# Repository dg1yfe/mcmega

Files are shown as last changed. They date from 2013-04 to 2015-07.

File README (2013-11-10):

MCmega is a port of the MC70 firmware to the AVR platform.
It provides an alternative firmware for Motorola MC micro transceivers to enable the use of those radios for HAM radio.
The project includes a PCB (printed ciruit board) with an ATMega64 which is designed to replace the original CPU on the GLN6628B/GLN6984A command board used in the MC micro model EZA9.

Check out the details on the projects homepage:
http://mc70.stus-disco.de

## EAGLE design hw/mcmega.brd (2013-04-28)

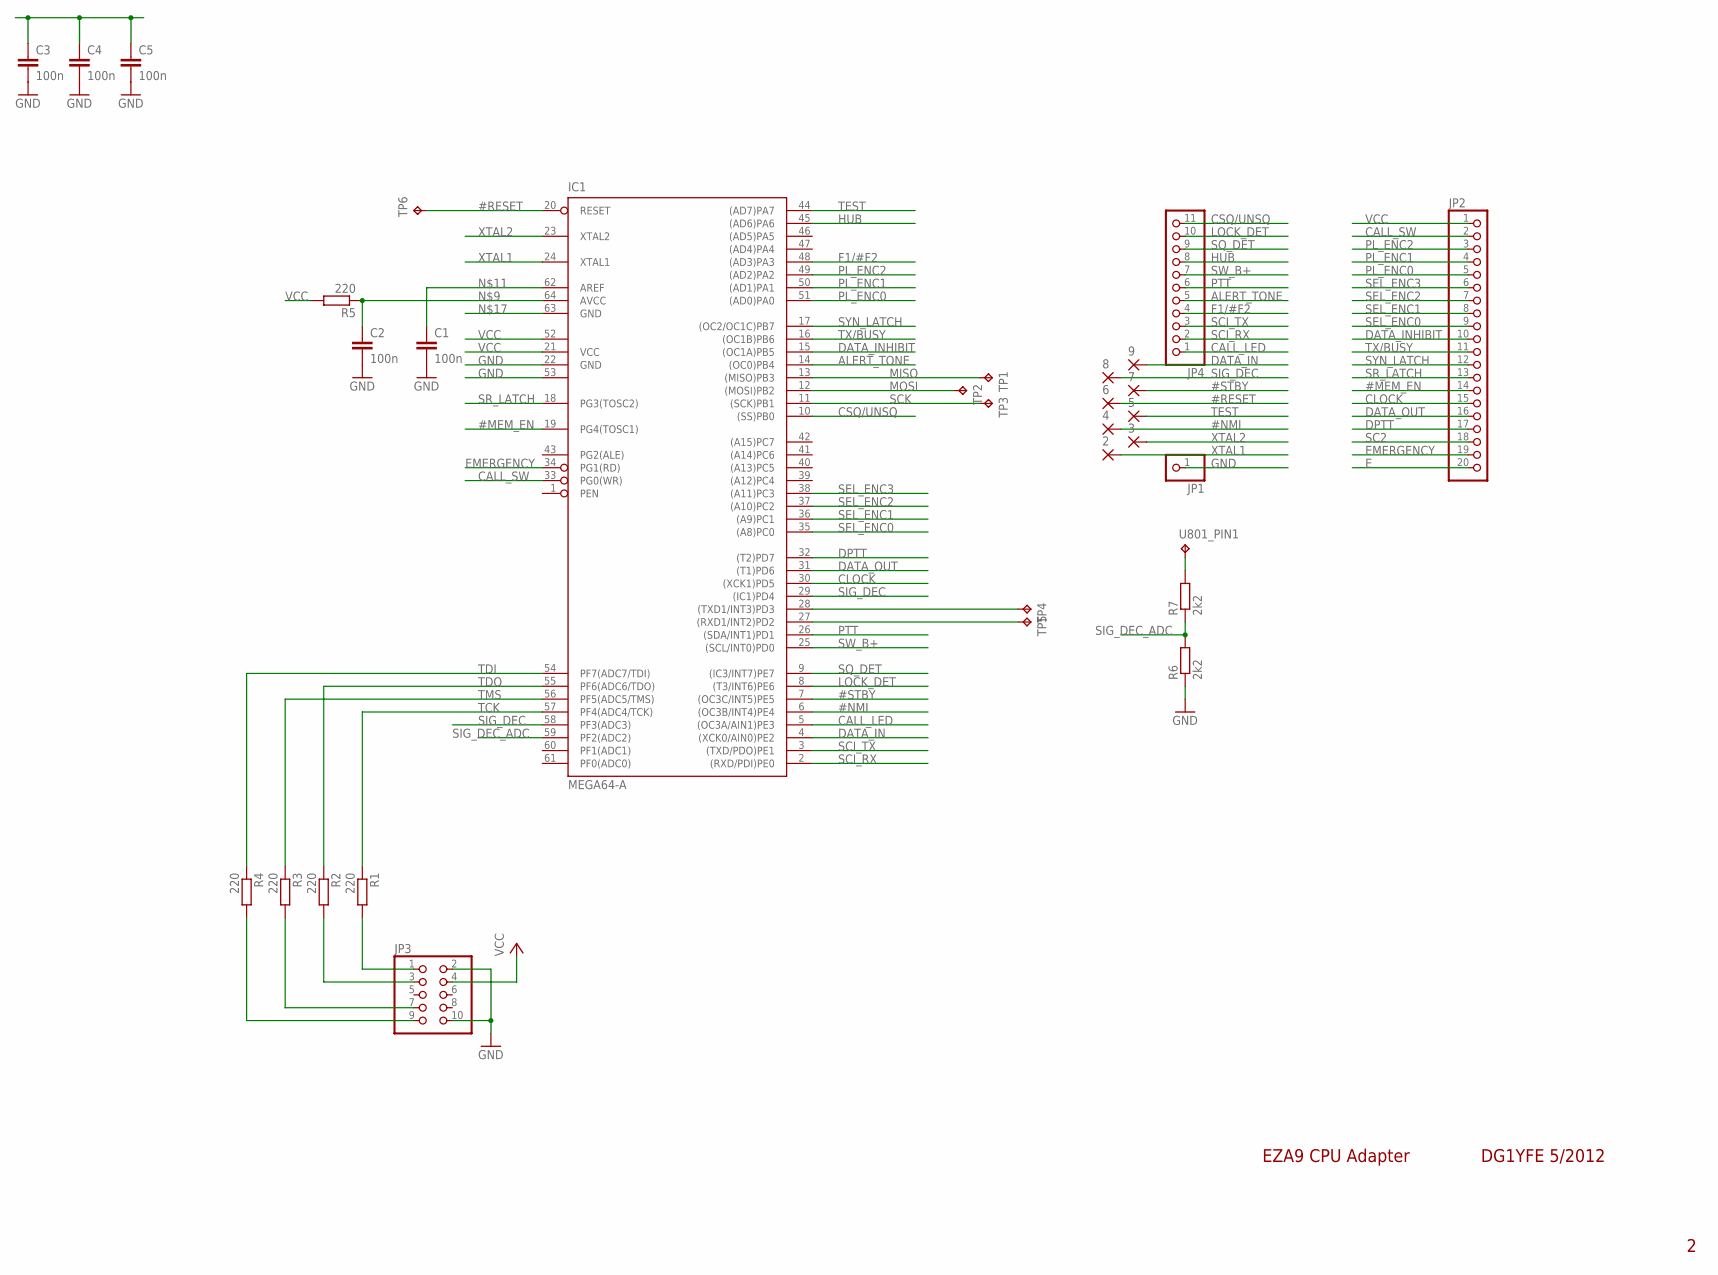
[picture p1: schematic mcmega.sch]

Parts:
2, 3, 4, 5, 6, 7, 8, 9: SMD2; SMD1,27-2,54
C1, C2, C3, C4, C5: 100n; C0603
IC1: MEGA64-A; TQFP64
JP1: PINHD-1X1; 1X01
JP2: PINHD-1X20; 1X20
JP3: PINHD-2X5; 2X05
JP4: PINHD-1X11; 1X11
R1, R2, R3, R4, R5: 220; R0603
R6, R7: 2k2; R0603
TP1, TP2, TP3, TP4, TP5, TP6: TPTP09R; TP09R
U801_PIN1: TPTP10R; TP10R

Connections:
#MEM_EN: IC1.19 (PG4(TOSC1)), JP2.14
#NMI: 4.1, IC1.6 ((OC3B/INT4)PE4)
#RESET: 6.1, IC1.20 (RESET), TP6.TP
#STBY: 7.1, IC1.7 ((OC3C/INT5)PE5)
ALERT_TONE: IC1.14 ((OC0)PB4), JP4.5
CALL_LED: IC1.5 ((OC3A/AIN1)PE3), JP4.1
CALL_SW: IC1.33 (PG0(WR)), JP2.2
CLOCK: IC1.30 ((XCK1)PD5), JP2.15
CSQ/UNSQ: IC1.10 ((SS)PB0), JP4.11
DATA_IN: 9.1, IC1.4 ((XCK0/AIN0)PE2)
DATA_INHIBIT: IC1.15 ((OC1A)PB5), JP2.10
DATA_OUT: IC1.31 ((T1)PD6), JP2.16
DPTT: IC1.32 ((T2)PD7), JP2.17
E: JP2.20
EMERGENCY: IC1.34 (PG1(RD)), JP2.19
F1/#F2: IC1.48 ((AD3)PA3), JP4.4
GND: C1.2, C2.2, C3.2, C4.2, C5.2, IC1.22 (GND), IC1.53 (GND1), JP1.1, JP3.2, JP3.10, R6.1
HUB: IC1.45 ((AD6)PA6), JP4.8
LOCK_DET: IC1.8 ((T3/INT6)PE6), JP4.10
MISO: IC1.13 ((MISO)PB3), TP1.TP
MOSI: IC1.12 ((MOSI)PB2), TP2.TP
unnamed: JP3.1, R1.2
unnamed: JP3.3, R2.2
unnamed: JP3.7, R3.2
unnamed: JP3.9, R4.2
unnamed: R7.2, U801_PIN1.TP
unnamed: C2.1, IC1.64 (AVCC), R5.1
unnamed: C1.1, IC1.62 (AREF)
unnamed: IC1.28 ((TXD1/INT3)PD3), TP4.TP
unnamed: IC1.27 ((RXD1/INT2)PD2), TP5.TP
PL_ENC0: IC1.51 ((AD0)PA0), JP2.5
PL_ENC1: IC1.50 ((AD1)PA1), JP2.4
PL_ENC2: IC1.49 ((AD2)PA2), JP2.3
PTT: IC1.26 ((SDA/INT1)PD1), JP4.6
SC2: JP2.18
SCI_RX: IC1.2 ((RXD/PDI)PE0), JP4.2
SCI_TX: IC1.3 ((TXD/PDO)PE1), JP4.3
SCK: IC1.11 ((SCK)PB1), TP3.TP
SEL_ENC0: IC1.35 ((A8)PC0), JP2.9
SEL_ENC1: IC1.36 ((A9)PC1), JP2.8
SEL_ENC2: IC1.37 ((A10)PC2), JP2.7
SEL_ENC3: IC1.38 ((A11)PC3), JP2.6
SIG_DEC: 8.1, IC1.29 ((IC1)PD4), IC1.58 (PF3(ADC3))
SIG_DEC_ADC: IC1.59 (PF2(ADC2)), R6.2, R7.1
SQ_DET: IC1.9 ((IC3/INT7)PE7), JP4.9
SR_LATCH: IC1.18 (PG3(TOSC2)), JP2.13
SW_B+: IC1.25 ((SCL/INT0)PD0), JP4.7
SYN_LATCH: IC1.17 ((OC2/OC1C)PB7), JP2.12
TCK: IC1.57 (PF4(ADC4/TCK)), R1.1
TDI: IC1.54 (PF7(ADC7/TDI)), R4.1
TDO: IC1.55 (PF6(ADC6/TDO)), R2.1
TEST: 5.1, IC1.44 ((AD7)PA7)
TMS: IC1.56 (PF5(ADC5/TMS)), R3.1
TX/BUSY: IC1.16 ((OC1B)PB6), JP2.11
VCC: C3.1, C4.1, C5.1, IC1.21 (VCC), IC1.52 (VCC1), JP2.1, JP3.4, R5.2
XTAL1: 2.1, IC1.24 (XTAL1)
XTAL2: 3.1, IC1.23 (XTAL2)

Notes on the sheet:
EZA9 CPU Adapter
DG1YFE 5/2012

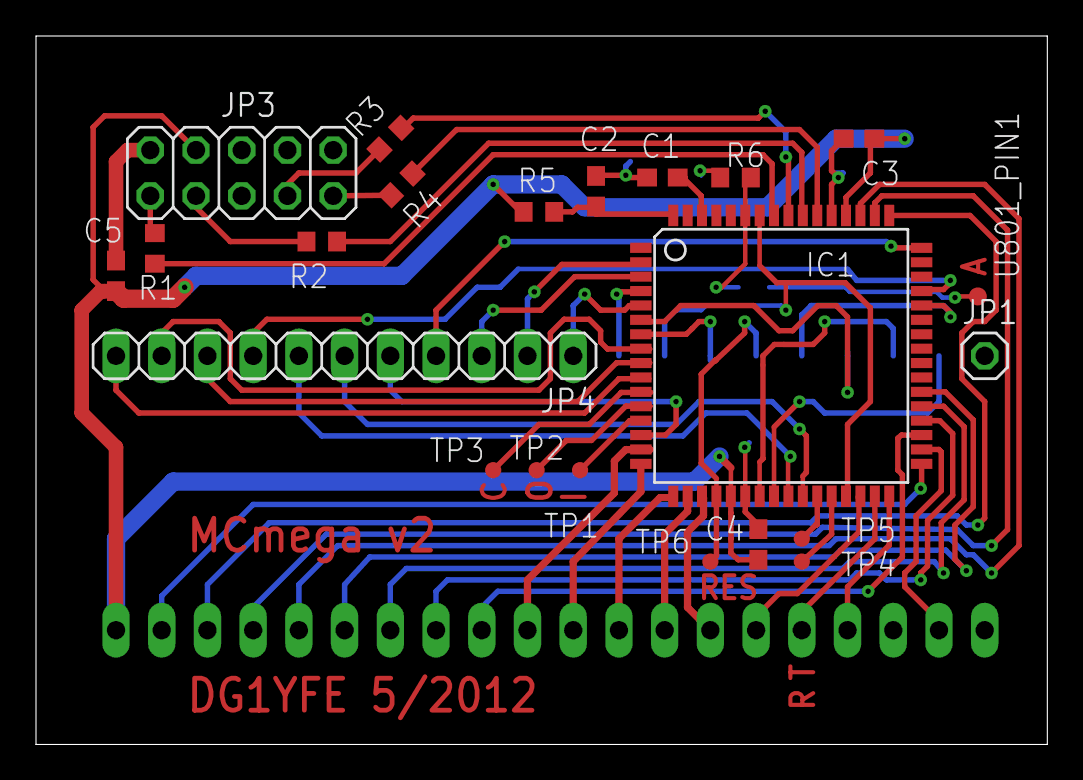
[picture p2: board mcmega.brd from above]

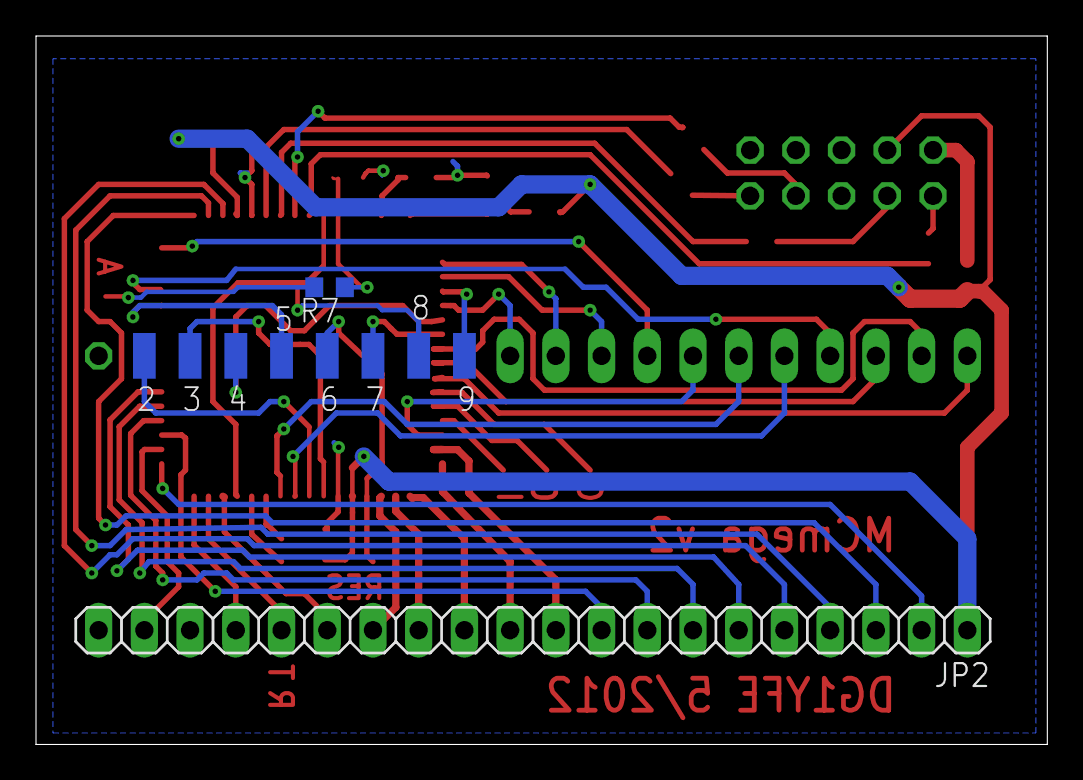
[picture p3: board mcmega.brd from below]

Board: 2 copper layers, 56.2 x 39.4 mm, 32 parts (10 on the bottom side), 55 nets.

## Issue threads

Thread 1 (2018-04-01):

Fuses missing

dg8ygz, 2018-04-01:
No Fuses for the ATMEGA were documented
if there's any additional info needed it would be helpful to know

73s

dg8ygz, 2018-04-01:
FUSES:
low:  **0xD4**
high: **0x10**
ext.:   **0xFF**

necessary:
(in AVR Studio 7)
/Toolchain/AVR GNU Compiler/ Symbols/
**F_CPU=8000000**

/Toolchain/AVR GNU Compiler/Optimization/
**set level to Size   (Os)**
other Flags:
**-Ttext=0xF800**

then it should work with the programm adapter shown here with 8N1 19200

tnx to dg1yfe for info

dg1yfe, 2018-04-02:
Bug and solution relates to https://github.com/dg1yfe/mcmboot/ .

Closed 2018-04-02.

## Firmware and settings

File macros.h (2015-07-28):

/*
 * macros.h
 *
 *  Created on: 26.05.2012
 *****************************************************************************
 *	MCmega - Firmware for the Motorola MC micro radio
 *           to use it as an Amateur-Radio transceiver
 *
 * Copyright (C) 2013 Felix Erckenbrecht, DG1YFE
 *
 * ( AVR port of "MC70"
 *   Copyright (C) 2004 - 2013  Felix Erckenbrecht, DG1YFE)
 *
 * This file is part of MCmega.
 *
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
 ****************************************************************************
 */
#ifndef MACROS_H_
#define MACROS_H_

#include "regmem.h"

#define EZA9

//#define BAND_2M
//#define BAND_70CM

// Timing
// Frequency of crystal in EVA5
#define XTAL F_CPU
// no scaling
#define SYSCLK XTAL
#define MENUTIMEOUT   40	// 4 sek Eingabetimeout
#define PLLCHKTIMEOUT 2		// 200ms Timeout für PLL Check
#define PTT_DEBOUNCE_VAL 20
#define TX_TO_RX_TIME 5		// 5 ms TX -> RX Umschaltung
#define RX_TO_TX_TIME 5  	// 5 ms RX -> TX Umschaltung

#define DEFAULT_RF_PWR 0	// Hi Power (1) / Lo Power (0), only EVA9/EZA9
//************************
// Frequenzkram
//
//
#define RXZF   UINT32_C(21400000)// 21,4 MHz IF (RX VCO has to be 21,4MHz below RX frequency)
#define FREF   UINT32_C(14400000)// 14,4 MHz reference frequency
#define FOFF0  UINT32_C(       0)// Offset0
#define FOFF06 UINT32_C(  600000)// Offset1
#define FOFF76 UINT32_C( 7600000)// Offset2
#define FSTEP  UINT32_C(   12500)// Schrittweite !> 3,5 kHz fuer f<458,3MHz 
								 //( muss groesser sein als Frequenz/(Vorteiler*1023) )
//
#define PLLREF FREF/FSTEP
#define PLLLOCKWAIT 200         // Maximale Wartezeit in ms f�r PLL um einzurasten

//#define FSTEP      6250        // Schrittweite !> 3,5 kHz f�r f<458,3MHz ( mu� gr��er sein als Frequenz/(128*1023) )
//#define PLLREF     1152
//#define PLLREF     2304

#ifdef BAND_70CM
#define FBASE UINT32_C(430000000)// lowest frequency (for eeprom storage) = 140MHz (430 MHz with 70 cm)
#define FBASE_MEM_RECALL UINT32_C(400000000)
#define FDEF  UINT32_C(433500000)// Default Frequency
#define FTXOFF FOFF76			// Default Offset = 7.6 MHz
#define PRESCALER   127         // PLL Prescaler (40 for 2m, 127 for 70cm)
#endif

#ifdef BAND_2M
#define FBASE UINT32_C(140000000)// lowest frequency (for eeprom storage) = 140MHz (430 MHz with 70 cm)
#define FBASE_MEM_RECALL UINT32_C(140000000)
#define FDEF  UINT32_C(145500000)// Default Frequency
#define FTXOFF FOFF06			 // Default Offset = 0.6 MHz
#define PRESCALER    40          // PLL Prescaler (40 for 2m, 127 for 70cm)
#endif

#if !defined BAND_2M && !defined BAND_70CM
#error No frequency band defined, define one in macros.h
#endif

//
//************************
// Squelch
//
#define SQL_HYST   10           // define squelch hysteresis in 5 ms steps
#define SQL_INTERVAL 150		// update squelch state every 150 ms
//
#define LCDDELAY  45     		// 42 ms

//************************
//Clock toggle


// **************************************************************
#define YEL_LED       0x31
#define GRN_LED       0x32
#define RED_LED       0x33

#define LED_OFF       0
#define LED_ON        4
#define LED_BLINK     8
#define LED_INVERT    128

#define ARROW         0x6D
#define A_OFF           0
#define A_ON            1
#define A_BLINK         2

//******************************************************************
#define P_SIGIN 1

//******************************************************************
// Blink Char
#define CHR_BLINK     0x80
// non printable chars
#define semikolon  0x3B
#define komma      0x2C
#define backslash  0x5C


//***********************
//
// Character Stuff
//
#define LCD_A     0x4A
#define LCD_ULINE 0x4B
#define LCD_SPACE 0x4C
//
//
// "segment type""pos hor""pos. vert""diagonal"
#define seg15left  0x4D
#define seg15right 0x4E
#define seg7       0x4E
#define segblink   0x10

#define seg15o   0x10
#define seg15lo  0x20
#define seg15lod 0x02
#define seg15lu  0x40
#define seg15u   0x01
#define seg15lud 0x08
#define seg15lm  0x04

#define seg15mo  0x20
#define seg15mu  0x40
#define seg15rod 0x04
#define seg15ro  0x01
#define seg15ru  0x02
#define seg15rud 0x10
#define seg15rm  0x08

#define seg7o  0x04
#define seg7m  0x08
#define seg7u  0x10
#define seg7lo 0x20
#define seg7lu 0x40
#define seg7ro 0x01
#define seg7ru 0x02

//4D - solid:
//5D - blink:
//Cursor bleibt stehen nach 0x4D/0x5D zur Ergänzung des Zeichens mit 0x4E/0x5E
//15Seg:
//    1010
//20 02 __ __ __
//20  02____  __
//  0404  ____
//40  08____  __
//40 08 __ __ __
//    0101

//4E - solid:
//5E - blink:
//Segment Codes

//7Seg:
//  04
//20  01
//  08
//40  02
//  10

//15Seg:
//     ____
//__ __ 20 04 01
//__  __2004  01
//  ____  0808
//__  __4010  02
//__ __ 40 10 02
//    ____
//


// Tastencodes - Dx = Taste unter Display, Nx=numerische Tasten
//
#define D1 0x01
#define D2 0x02
#define D3 0x03
#define D4 0x04
#define D5 0x05
#define D6 0x06
#define D7 0x07
#define D8 0x08
#define CLEAR 0x14
#define N1 0x11
#define N2 0x0D
#define N3 0x09
#define N4 0x12
#define N5 0x0E
#define N6 0x0A
#define N7 0x13
#define N8 0x0F
#define N9 0x0B
#define STERN 0x14
#define N0 0x10
#define RAUTE 0x0C

#define KC_NONE 0xff
#define KC_D1 0x11
#define KC_D2 0x12
#define KC_D3 0x13
#define KC_D4 0x14
#define KC_D5 0x15
#define KC_D6 0x16
#define KC_D7 0x17
#define KC_D8 0x18
#define KC_ENTER 0x10
#define KC_EXIT  0x19
#define KC_NON_NUMERIC 0x10
#define KC_STAR 0x19
#define KC_HASH 0x10

/*
 * Control Head definitions, used for key convert table
 */
#define CONTROL_HEAD3 0
#define CONTROL_HEAD2 1

/*
 * ;****************************************************************************
;
;    MC70 - Firmware for the Motorola MC micro trunking radio
;           to use it as an Amateur-Radio transceiver
;
;    Copyright (C) 2004 - 2011  Felix Erckenbrecht, DG1YFE
;
;     This file is part of MC70.
;
;     MC70 is free software: you can redistribute it and/or modify
;     it under the terms of the GNU General Public License as published by
;     the Free Software Foundation, either version 3 of the License, or
;     (at your option) any later version.
;
;     MC70 is distributed in the hope that it will be useful,
;     but WITHOUT ANY WARRANTY; without even the implied warranty of
;     MERCHANTABILITY or FITNESS FOR A PARTICULAR PURPOSE.  See the
;     GNU General Public License for more details.
;
;     You should have received a copy of the GNU General Public License
;     along with MC70.  If not, see <http://www.gnu.org/licenses/>.
;
;
;
;****************************************************************************
#DEFINE EVA5
;#DEFINE EVA9
;#DEFINE 2M
;#DEFINE 70CM

;******************************************************************
; Blink Char
#DEFINE CHR_BLINK     $80
; non printable chars
#DEFINE semikolon  $3B
#DEFINE komma      $2C
#DEFINE backslash  $5C


#DEFINE WAIT(ms)    pshx \ ldx  #ms \ jsr wait_ms \ pulx
#DEFINE LCDDELAY  42     ; 41ms
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

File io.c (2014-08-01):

/*
 * io.c
 *
 *  Created on: 26.05.2012
 *****************************************************************************
 *	MCmega - Firmware for the Motorola MC micro radio
 *           to use it as an Amateur-Radio transceiver
 *
 * Copyright (C) 2013 Felix Erckenbrecht, DG1YFE
 *
 * ( AVR port of "MC70"
 *   Copyright (C) 2004 - 2013  Felix Erckenbrecht, DG1YFE)
 *
 * This file is part of MCmega.
 *
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
 ****************************************************************************
 */
#include <stdlib.h>
#include <stdio.h>
#include <stdint.h>
#include <string.h>
#include <avr/io.h>
#include <avr/pgmspace.h>
#include <util/delay.h>

#include "FreeRTOS.h"
#include "task.h"
#include "semphr.h"
#include "queue.h"


#include "macros.h"
#include "regmem.h"
#include "firmware.h"
#include "display.h"


// serial bus maximum frequency in kHz
// the maximum rate is limited by RC low-pass-filters
// towards PLL: R = 12k7, C = (68 pF + 10 pF) -> Tau = 0.99 us
// -> rise time & fall time must be >= 5*Tau
// -> clock period = 5*0.99 -> 10 us -> 100 kHz
#ifdef DEBUG_BUILD
// make it faster for debug builds due to missing optimization
#define SBUS_PLL_CLOCK 500
#else
#define SBUS_PLL_CLOCK 100
#endif
#define SBUS_PLL_DELAY  (1000/SBUS_PLL_CLOCK)
#define SBUS_PLL_DELAY2 (SBUS_PLL_DELAY/2)


void SetShiftReg(uint8_t or_value, uint8_t and_value);
void men_buf_write( char data );

void sci_read_cmd(void);

void pputchar(char mode, char data, char * extdata);

static char pc_cache(char data);
static void sendnibble( char data);
static void store_dbuf(char data);
void uinthex( const char data);
void uintdec(char data);
void ulongout(char modif, char * data);
void decout(uint8_t modif, uint8_t truncate, char * data);

int putchar_wrapper (char c, FILE *stream);

xSemaphoreHandle TxDone;
xSemaphoreHandle SerialBusMutex;
xQueueHandle xRxQ, xRxKeyQ, xTxQ;

uint8_t tx_stall = 0;
uint8_t ch_reset_detected;

struct S_TxChar{
	char data;
	uint8_t delay;
};

static FILE mystdout = FDEV_SETUP_STREAM(putchar_wrapper, NULL,
										 _FDEV_SETUP_WRITE);

const unsigned int char_convert[] PROGMEM = {
		0x004C, 0x4E60, 0x4E21, 0x4D45, 0x4D35, 0x4D28, 0x4D47, 0x4E20,
		0x4D71, 0x4D11, 0x4F29, 0x4F28, 0x4D08, 0x4D04, 0x4D01, 0x4D08,
		0x0040, 0x0041, 0x0042, 0x0043, 0x0044, 0x0045, 0x0046, 0x0047,
		0x0048, 0x0049, 0x4D11, 0x4D18, 0x4E14, 0x4D05, 0x4D0A, 0x4F27,
		0x4D75, 0x4F0D, 0x4F0E, 0x4F0F,	0x4F10, 0x4F11, 0x4F12, 0x4F13,
		0x4F14, 0x4F15,	0x4F16, 0x4F17, 0x4F18, 0x4F19, 0x4F1A, 0x4F1B,
		0x4F1C, 0x4F1D, 0x4F1E, 0x4F1F, 0x4F20, 0x4F21,	0x4F22, 0x4F23,
		0x4F24, 0x4F25, 0x4F26, 0x4D71,	0x4D02, 0x4D11, 0x4E05, 0x004B,
		0x4D02, 0x004A, 0x4F0E, 0x4F0F, 0x4F10, 0x4F11, 0x4F12,	0x4F13,
		0x4F14, 0x4F15, 0x4F16, 0x4F17, 0x4F18,	0x4F19, 0x4F1A, 0x4F1B,
		0x4F1C, 0x4F1D, 0x4F1E,	0x4F1F, 0x4F20, 0x4F21, 0x4F22, 0x4F23,
		0x4F24,	0x4F25, 0x4F26, 0x4D71, 0x4E60, 0x4D11, 0x4D22, 0x004C
};

const char e_char_convert[] PROGMEM = {
		0x00,  0x00,  0x00,  0x0A,  0x6A,  0x06,  0x50,  0x00,
		0x00,  0x03,  0x00,  0x00,  0x00,  0x08,  0x00,  0x04,
		0x40,  0x41,  0x42,  0x43,  0x44,  0x45,  0x46,  0x47,
		0x48,  0x49,  0x00,  0x00,  0x00,  0x08,  0x00,  0x00,
		0x09,  0x0D,  0x0E,  0x0F,  0x10,  0x11,  0x12,  0x13,
		0x14,  0x15,  0x16,  0x17,  0x18,  0x19,  0x1A,  0x1B,
		0x1C,  0x1D,  0x1E,  0x1F,  0x20,  0x21,  0x22,  0x23,
		0x24,  0x25,  0x26,  0x00,  0x10,  0x03,  0x00,  0x00,
		0x00,  0x0D,  0x0E,  0x0F,  0x10,  0x11,  0x12,  0x13,
		0x14,  0x15,  0x16,  0x17,  0x18,  0x19,  0x1A,  0x1B,
		0x1C,  0x1D,  0x1E,  0x1F,  0x20,  0x21,  0x22,  0x23,
		0x24,  0x25,  0x26,  0x00,  0x00,  0x03,  0x03,  0x04
};

const char key_convert[2][21] PROGMEM = {
	// Control Head #3
	//     ---------------------------  1   2   3
	//     !                         !
	// D1  !                         !  4   5   6
	//     !                         !
	// D2  !                         !  7   8   9
	//     ---------------------------
	//     D3  (D4)  D5  (D6)  D7  (D8) *   0   #
	//
	// --,   D1,   D2,   D3,   D4,   D5,   D6,   D7,   D8,
	{0x00, 0x11, 0x12, 0x13, 0x14, 0x15, 0x16, 0x17, 0x18,
	//  3, 6, 9,    #   , 2, 5,  8, 0, 1, 4, 7,    *
		3, 6, 9,KC_ENTER, 2, 5,  8, 0, 1, 4, 7, KC_EXIT},

	// Control Head #2
	//     ---------------------------
	//     !                         !
	// D1  !                         !    5
	//     !                         !
	// D2  !                         !    8
	//     ---------------------------
	//     D3   D4   D5   D6   D7   D8
	//
	// --,   D1,   D2,   D3,   D4,   D5,   D6,   D7,   D8,
	{0x00,KC_D1,KC_D2,KC_D3,KC_D4,KC_D5,KC_D6,KC_D7,KC_D8,
	//  3, 6, 9,    #,    2,    5   ,     8   , 0, 1, 4, 7,    *
	    3, 6, 9,KC_ENTER, 2, KC_EXIT, KC_ENTER, 0, 1, 4, 7, KC_EXIT},
};


/*
;****************
; I O   I N I T
;****************
;
; Initialisiert I/O :
;                     - Port2 DDR ( SCI TX, PLL T/R Shift )
;                     - Port6 DDR ( PTT Syn Latch )
;                     - Port5 DDR ( EXT Alarm )
;                     - Port5 Data ( EXT Alarm off (1) )
;                     - RP5CR (HALT disabled)
;                     - I2C (Clock output, Clock=0)
;                     - Shift Reg (S/R Latch output, S/R Latch = 0, S/R init)
;                     - SCI TX = 1 (Pullup)
io_init
                aim  #%11100111,RP5CR     ; nicht auf "Memory Ready" warten, das statische RAM ist schnell genug
                                          ; HALT Input auch deaktivieren, Port53 wird später als Ausgang benötigt

                ldab #%10110100
                stab Port2_DDR_buf             ; Clock (I2C),
                stab Port2_DDR                 ; SCI TX, T/R Shift (PLL), Shift Reg Latch auf Ausgang

; I2C Init
                aim  #%11111011,Port2_Data     ; I2C Clock = 0
;ShiftReg Init
                aim  #%01111111,Port2_Data     ; Shift Reg Latch = 0
;SCI TX
                oim  #%10000, Port2_Data       ; SCI TX=1

                clr  SR_data_buf               ; Shuft Reg Puffer auf 0 setzen

                ldaa #~(SR_RFPA)               ; disable PA
                ldab #(SR_nTXPWR + SR_nCLKSHIFT + SR_9V6)
                                               ; disable Power control, disable clock shift, enable 9,6 V
                jsr  send2shift_reg

; Port 5
                ldab #%00001000
                stab SQEXTDDR                  ; EXT Alarm auf Ausgang, Alles andere auf Input
                stab SQEXTDDRbuf
                oim  #%00001000, SQEXTPORT     ; EXT Alarm off (Hi)

; Port 6
                ldab #%00001100
                stab Port6_DDR_buf
                stab Port6_DDR                 ; A16 (Bank Switch), PTT Syn Latch auf Ausgang

                aim  #%10011011, Port6_Data    ; Bank 0 wählen

                clr  led_buf
                clr  arrow_buf
                clr  arrow_buf+1

                clr  sql_ctr
                clr  ui_ptt_req             ;
                rts


 *
 */
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

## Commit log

2012-07-12 timer.c / math.c, some fixes, some extensions
    [io.c, io.h, macros.h]
2012-07-13 Compiles for the first time ... needs bugfixing!
    [eeprom.c, io.c, io.h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]
2012-07-15 fixed includes switched to avr-gcc 4.5.1, changed code to compile (removed inline stuff for now, etc...)
    [eeprom.c, io.h]
2012-07-17 Some Bugfixes, changes for debugging
    [io.c, subs.c]
2012-07-17 Put HW files in HW folder
    [mcmega.brd, mcmega.sch]
2012-07-17 Updated HW files
    [mcmega.brd, mcmega.sch]
2012-07-18 Bugfix regarding UART rx, debugging LCD Reset & Comm
    [io.c]
2012-07-19 Further changes to comm handling, control head comm still broken
    [io.c, macros.h]
2012-07-20 more work on comm, still broken
    [io.c, macros.h, regmem.h]
2012-07-20 Possibly fixed tx comm issue, needs testing
    [io.c, macros.h]
2012-07-20 Fixed bugs related to comm, key input and LED setting
    [io.c, io.h, macros.h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]
2012-07-20 Bugfix in eep_seq_read(), fixed deadlock
    [eeprom.c]
2012-07-20 Implemented freq_init(), bugfix in pll_set_channel(), improved comm handling (regarding successive keypresses), etc...
    [io.c, macros.h, subs.c]
2012-07-21 Implemented display/control head reset & reinitialization during operation (e.g. CH was powered down without resetting radio)
    [io.c, io.h]
2012-07-21 Bugfix: PLL lock state was not displayed
    [regmem.h]
2012-07-22 Fixed serial bus access (timing, signal integrity), bugfix in set_pll() (did not set correct divider)
    [int.c, io.c, macros.h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]
2012-07-22 Bugfix: SWB check tested 'PORT' instead of 'PIN'
    [regmem.h, subs.c]
2012-07-22 Fixed UI related bugs (frequency & shift input, output functions, etc.), Improved lcd_fill: Only restore cpos, if cpos changed
    [io.c, macros.h, regmem.h]
2012-07-22 Bugfix: PTT was not read correctly, Bugfix: TX frequency was not set correct (division result was not used)
    [io.h, regmem.h, subs.c]
2012-07-22 Bugfix in lcd comm (0x4c / 0x5c were recognized as extended char), Bugfixes for menu/submenu function calls, Bugfixes for I2C comm., Implemented rfpwr_set() & rfpwr_print() and macro for default rf p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
    [io.c, macros.h]
2012-07-23 Bugfixes regarding recall & store menu and EEPROM comm.
    [eeprom.c, io.c, io.h]
2012-07-24 Bugfix in EEPROM access, included support for internal EEPROM, TODO: Implement function to transfer original channel data from ext. EEPROM to internal EEPROM
    [eeprom.c, subs.c]
2012-07-26 Bugfixes in Audio output, CTCSS TX and 1750 Hz now working, added calibration submenu to tune internal RC Oscillator (required for CTCSS to work)
    [audio.c, int.c]
2012-07-31 Included tone decoding, Included HW reset of control head
    [audio.c, int.c, io.h]
2012-08-01 Included 270 Hz IIR lowpass
2012-08-03 Bugfixes & optimizations for tone decoding
    [audio.c]
2012-08-05 Some bugifxes in audio processing
    [audio.c]
2013-02-27 Implement goertzel using floating point, use CIC decimation to reduce sample-rate, use chebychev low-pass for amplitude correction (WORK IN PROGRESS)
    [audio.c]
2013-03-03 Tone detection works, speed-up in main-loop - only yield if sample buffer is nearly empty, test-code still in place
2013-04-28 Include extra input and voltage divider for connection U801/Pin1 to ADC (enhanced signal detection)
    [mcmega.brd, mcmega.sch]
2013-04-29 Use ADC for tone detection, reset tone decoder on squelch pin rising edge
    [audio.c, int.c, regmem.h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]
2013-11-18 Bugfix: Enable watchdog, select correct bit to toggle. Enable yellow LED on RX (Busy LED)
    [subs.c]
2013-11-18 Remove fix setting of OSCCAL (TODO: Perform proper read-out of calibration data / perform proper calibration / Use external Xtal oscillator, update version info, put version info in one place
2014-03-17 Some fixes regarding shift settings
    [io.c]
2014-04-28 Bugfix: Disable yellow LED when squelch is closed
2014-04-28 Bugfix: Limit PLL datarate: PLL was not properly programmed when compiled with optimizations activated due to rise-time & fall-time violations
    [io.c]
2014-04-28 Bugfix: Disable yellow LED when NOT receiving or transmitting (now for real ;) )
    [subs.c]
2014-05-01 Optimize samplerate for 4.9 MHz, do not use chebychev filter for CIC roll-off compensation to save CPU time
2014-05-01 Define INCLUDE_xTaskGetCurrentTaskHandle to be able to determine the currently running task
2014-05-01 Bugfixes related to new config scheme (fix CRC calculation, fix passing of squelch & power cfg, fix frequency input handling)
    [subs.c]
2014-05-02 Updates & fixes to config handling. There is only one config structure, UI task is only allowed to read, Updates come as messages
    [subs.c]
2014-05-04 Bugfixes & cleanup regarding configuration, update EEPROM config only if it differs from SRAM, initialize squelch from config and no longer in menu_init()
    [io.c, regmem.h, subs.c]
2014-05-04 Feature: Add direct DTMF output during tx for buttons 0-9, * and #
2016-09-07 Rename MATH_H_ to MCM_MATH_H_ and include fast float prototypes
